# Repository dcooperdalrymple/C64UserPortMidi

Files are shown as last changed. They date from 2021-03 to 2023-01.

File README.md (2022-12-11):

# Commodore 64 User Port Midi Device
> Simple Midi Input & Output via the Commodore 64 User Port Interface<br />
> Created by D Cooper Dalrymple 2021 - [dcdalrymple.com](https://dcdalrymple.com/)<br />
> Licensed under GNU GPL V3.0<br />

I found myself in possession of a Commodore SX-64 and a desire to make music with it. After quickly finding [Cynthcart](https://www.qotile.net/cynthcart.html), I wasn't too happy about the idea of plugging both the Cynthcart cartridge and a separate Datel midi cartridge into in a [Mini X-Pander+](http://www.arkanixlabs.com/minixpander/) all sticking out of the hood of my SX-64. I had assumed that the User Port would have been a great interface for transmitting the necessary midi input data to whatever SID program you're jamming with. That's where this project comes in.

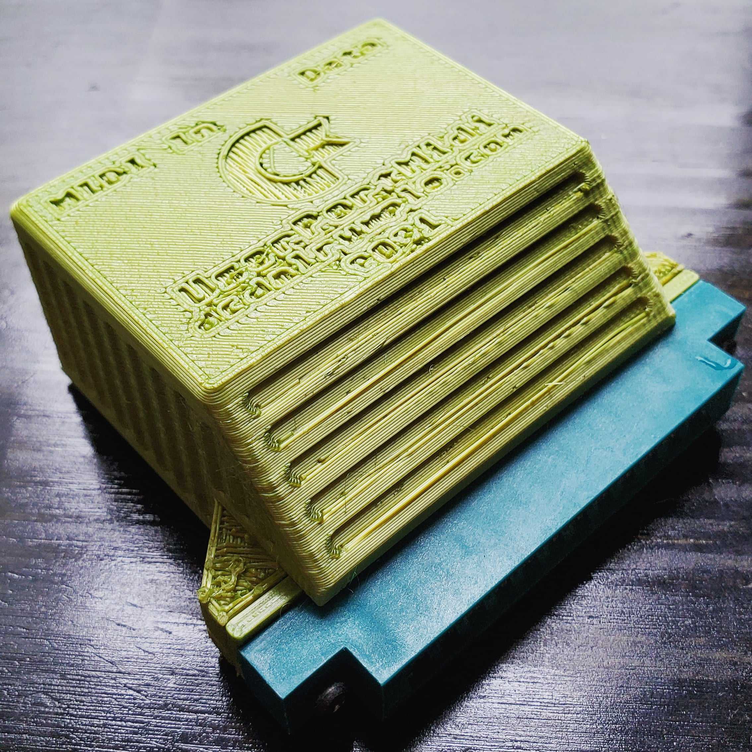
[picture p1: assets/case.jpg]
First development unit of C64UserPortMidi with 3d-printed case


## Functionality
The concept is fairly simple: the stream of data from the midi input will be piped into a buffer by the microcontroller. After representing the value of each byte on the data bus of the user port (PB0-7), it will then trigger the user port's flag interrupt (FLAG2) to indicate new data is available. The compatible Commodore software that has an interrupt registered for the user port's flag pin then adds that 8-bit data register to a data buffer. The midi information would then need to be processed by the main loop of the software. Easy peasy!

I am aware that there are serial lines available on the user port that have been used for RS-232 communication and such, but I wanted to use the least amount of resources when transferring data from the bus to the Commodore software. A simple `lda $DD01` is all that is necessary to get the full byte during a flag interrupt.

The 8 bits of the user port are bi-directionally connected to the microcontroller, and a data transfer back to the microcontroller can be flagged using the dedicated GPIO pin, PC2. This functionality can be used to send midi data back out through the Midi Out port and perform additional functionality that has yet to be developed (channel filters, etc).

## Components
The microcontroller chosen for this project is the ATtiny2313. Using this micro reduces the total BOM by not requiring an external crystal oscillator, operating at 5V, including a hardware UART controller, and having just the right amount of GPIO.

Overall, the BOM is fairly minimal and using only through-hole components for easy assembly. To quickly get started making your own, I've assembled a [Digikey shared cart](https://www.digikey.com/short/7djhm4fz) with the exact hardware requirements and all of the necessary gerber files to order your own PCBs from a distributor such as PCBway.

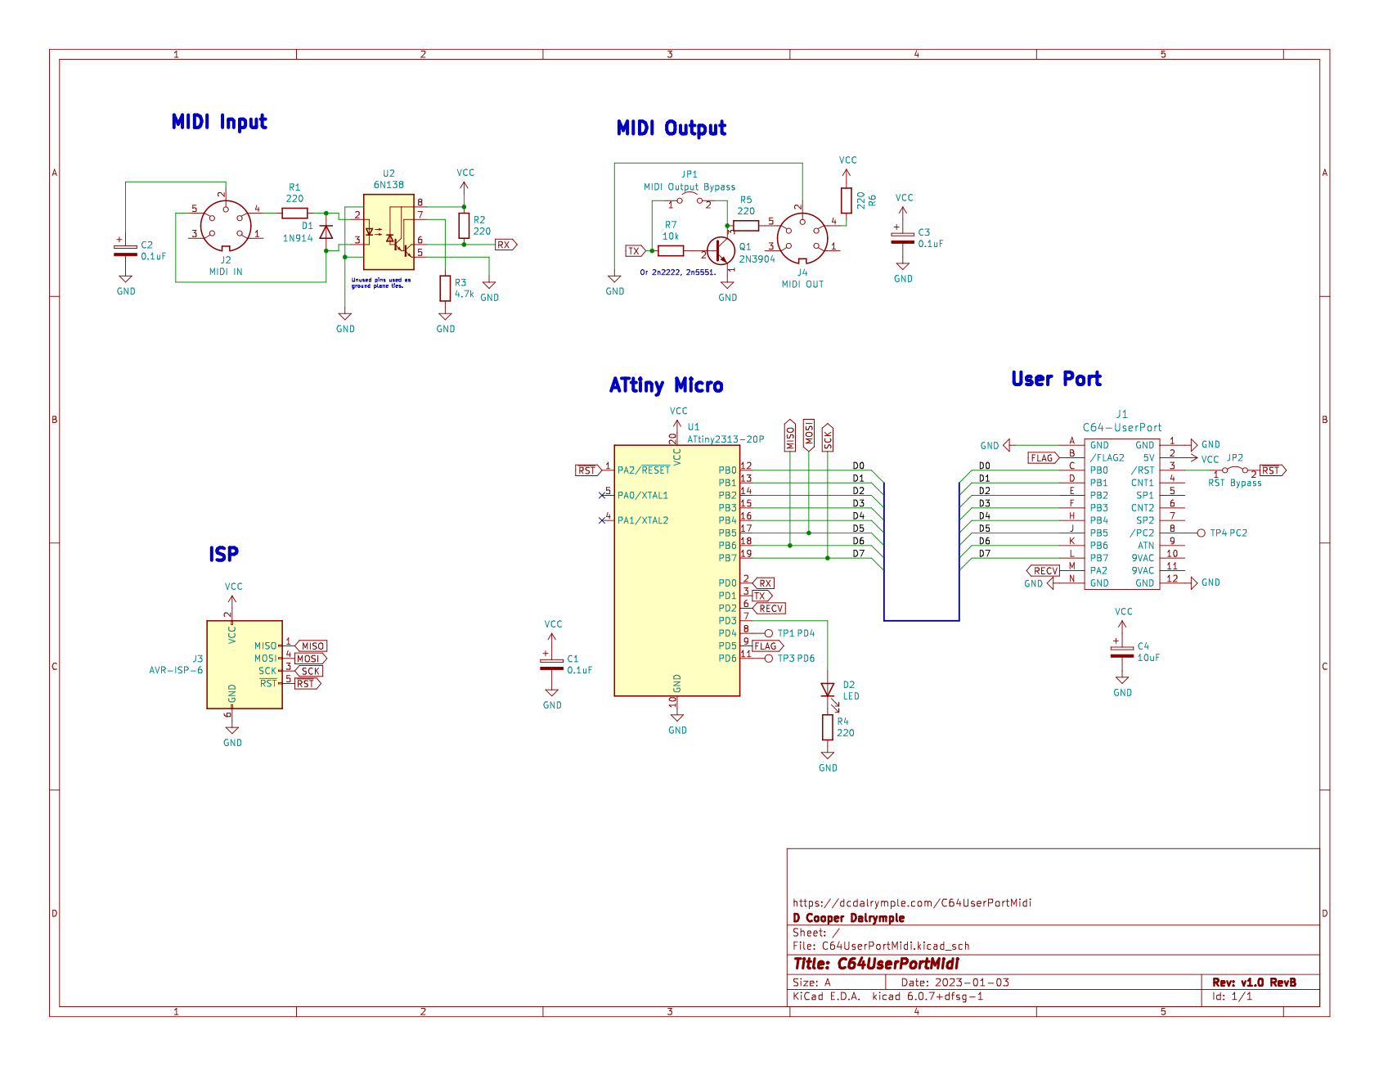
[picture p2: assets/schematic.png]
Schematic of C64UserPortMidi v1.0 RevA


## Development Status
I've just completed revision A of the hardware design which migrated from the ATtiny13 to ATtiny2313 and removed the need for a shift register. I've also added the components required MIDI output since the new microcontroller should be able to handle UART transmission with ease.

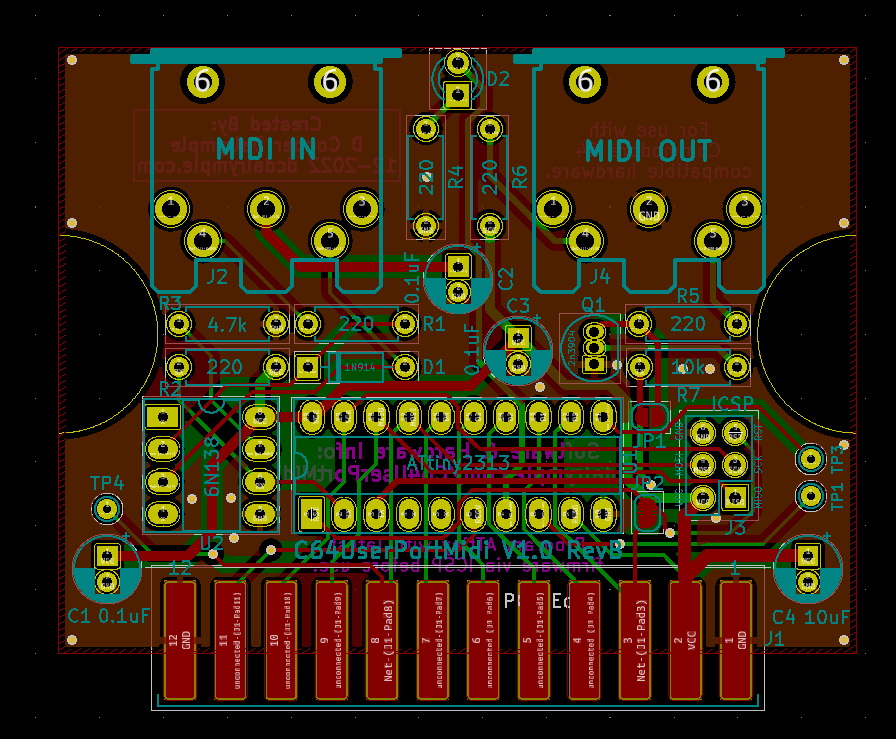
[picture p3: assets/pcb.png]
PCB Design of C64UserPortMidi v1.0 RevA


The firmware hasn't yet been updated for this new board design, but the functionality should mostly remain the same within the C64 software. I'll provide examples of bidirectional data transfer showcasing the output functionality of the new board once any bugs have been worked out.

I advise from producing your own units until the hardware and software have been fully developed.

## Software
A testing cartridge for the C64 is in development and mostly complete. This easily fits on a small 4kb/8kb lo-rom cart and could be compiled for floppy if needed. It can be run in emulation, but it isn't very useful unless the debugging data is enabled.

I plan to fork the Cynthcart repo once testing is completed to include full compatibility with this device.

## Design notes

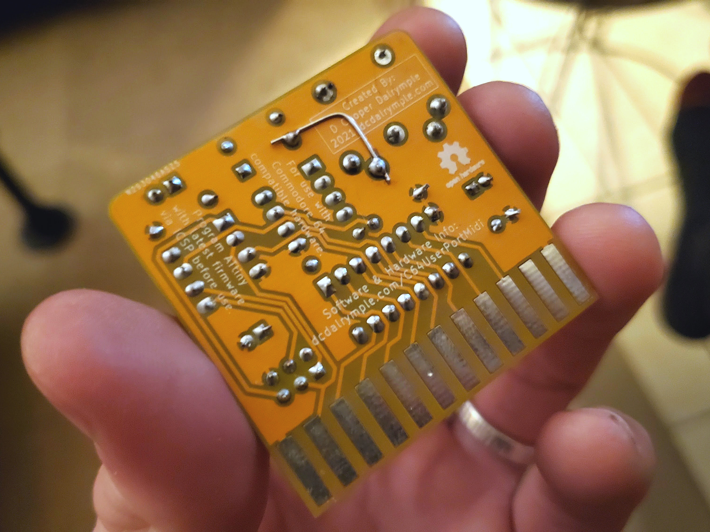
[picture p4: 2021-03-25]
assets/back.jpg

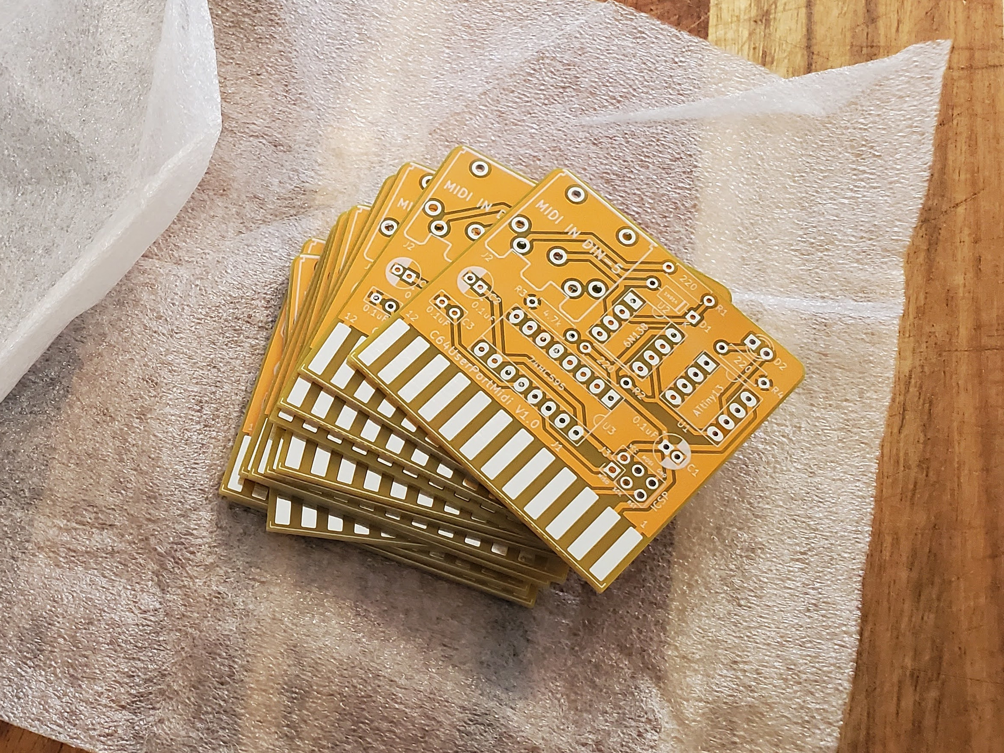
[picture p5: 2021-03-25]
assets/pcbs.jpg

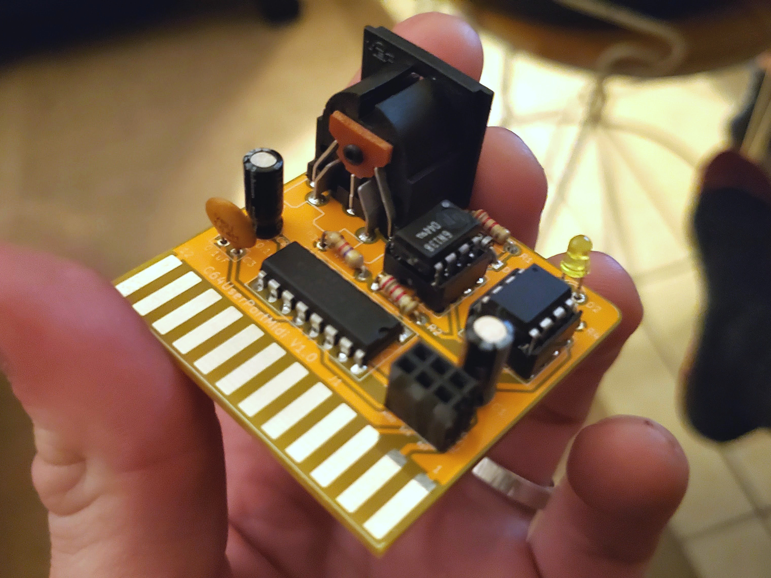
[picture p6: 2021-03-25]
assets/edge.jpg

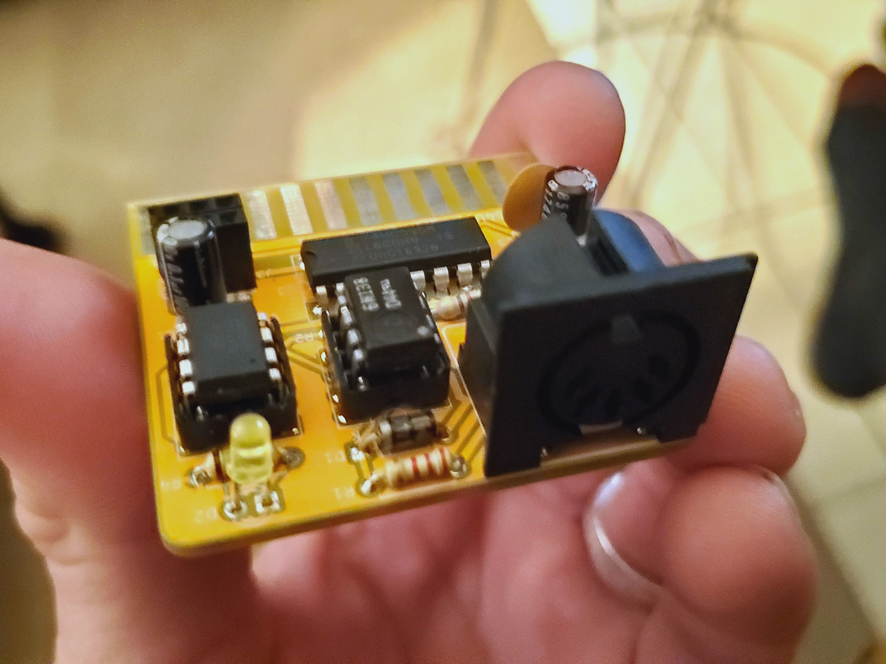
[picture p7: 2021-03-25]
assets/ports.jpg

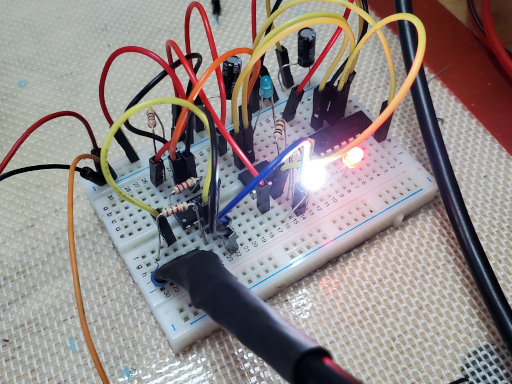
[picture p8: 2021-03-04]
assets/prototype.jpg

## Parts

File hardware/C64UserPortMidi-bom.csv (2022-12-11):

Reference | Value | Footprint | Datasheet
C1 | 0.1uF | Capacitor_THT:CP_Radial_D5.0mm_P2.00mm
C2 | 0.1uF | Capacitor_THT:CP_Radial_D5.0mm_P2.00mm
C3 | 0.1uF | Capacitor_THT:CP_Radial_D5.0mm_P2.00mm
C4 | 10uF | Capacitor_THT:CP_Radial_D5.0mm_P2.00mm
D1 | 1N914 | Diode_THT:D_DO-35_SOD27_P7.62mm_Horizontal | http://www.vishay.com/docs/85622/1n914.pdf
D2 | LED | LED_THT:LED_D3.0mm
J1 | C64-UserPort | Commodore64C:Connector_Edge_2x12_P3.96mm
J2 | MIDI IN | Video Connectors:din-5 | http://www.mouser.com/ds/2/18/40_c091_abd_e-75918.pdf
J3 | AVR-ISP-6 | Connector_PinHeader_2.54mm:PinHeader_2x03_P2.54mm_Vertical | ~
J4 | MIDI OUT | Video Connectors:din-5 | http://www.mouser.com/ds/2/18/40_c091_abd_e-75918.pdf
JP1 | MIDI Output Bypass | Jumper:SolderJumper-2_P1.3mm_Open_RoundedPad1.0x1.5mm
JP2 | RST Bypass | Jumper:SolderJumper-2_P1.3mm_Bridged_RoundedPad1.0x1.5mm
Q1 | 2N3904 | Package_TO_SOT_THT:TO-92_Inline | https://www.onsemi.com/pub/Collateral/2N3903-D.PDF
R1 | 220 | Resistor_THT:R_Axial_DIN0207_L6.3mm_D2.5mm_P7.62mm_Horizontal
R2 | 220 | Resistor_THT:R_Axial_DIN0207_L6.3mm_D2.5mm_P7.62mm_Horizontal
R3 | 4.7k | Resistor_THT:R_Axial_DIN0207_L6.3mm_D2.5mm_P7.62mm_Horizontal
R4 | 220 | Resistor_THT:R_Axial_DIN0207_L6.3mm_D2.5mm_P7.62mm_Horizontal
R5 | 220 | Resistor_THT:R_Axial_DIN0207_L6.3mm_D2.5mm_P7.62mm_Horizontal
R6 | 220 | Resistor_THT:R_Axial_DIN0207_L6.3mm_D2.5mm_P7.62mm_Horizontal
R7 | 10k | Resistor_THT:R_Axial_DIN0207_L6.3mm_D2.5mm_P7.62mm_Horizontal
TP1 | PD4 | TestPoint:TestPoint_THTPad_D1.5mm_Drill0.7mm
TP3 | PD6 | TestPoint:TestPoint_THTPad_D1.5mm_Drill0.7mm
TP4 | PA2 | TestPoint:TestPoint_THTPad_D1.5mm_Drill0.7mm
U1 | ATtiny2313-20P | Package_DIP:DIP-20_W7.62mm_Socket_LongPads | http://ww1.microchip.com/downloads/en/DeviceDoc/Atmel-2543-AVR-ATtiny2313_Datasheet.pdf
U2 | 6N138 | Package_DIP:DIP-8_W7.62mm_Socket_LongPads | http://www.onsemi.com/pub/Collateral/HCPL2731-D.pdf

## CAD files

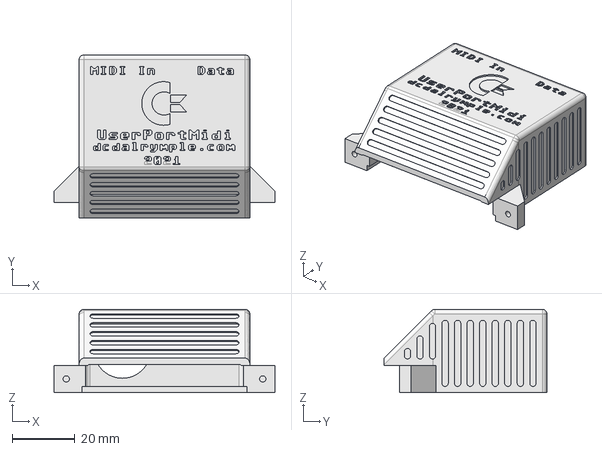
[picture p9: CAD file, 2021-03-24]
case/C64UserPortMidi-case.FCStd
70.5 x 52.0 x 26.6 mm

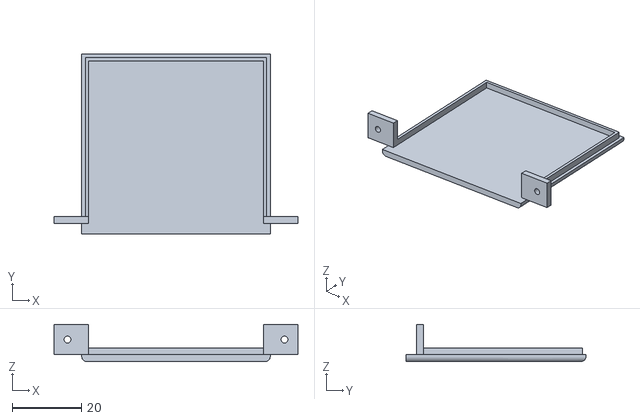
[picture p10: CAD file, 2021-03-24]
case/C64UserPortMidi-case-bottom.stl
70.5 x 52.0 x 10.8

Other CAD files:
case/C64UserPortMidi-case-top.stl

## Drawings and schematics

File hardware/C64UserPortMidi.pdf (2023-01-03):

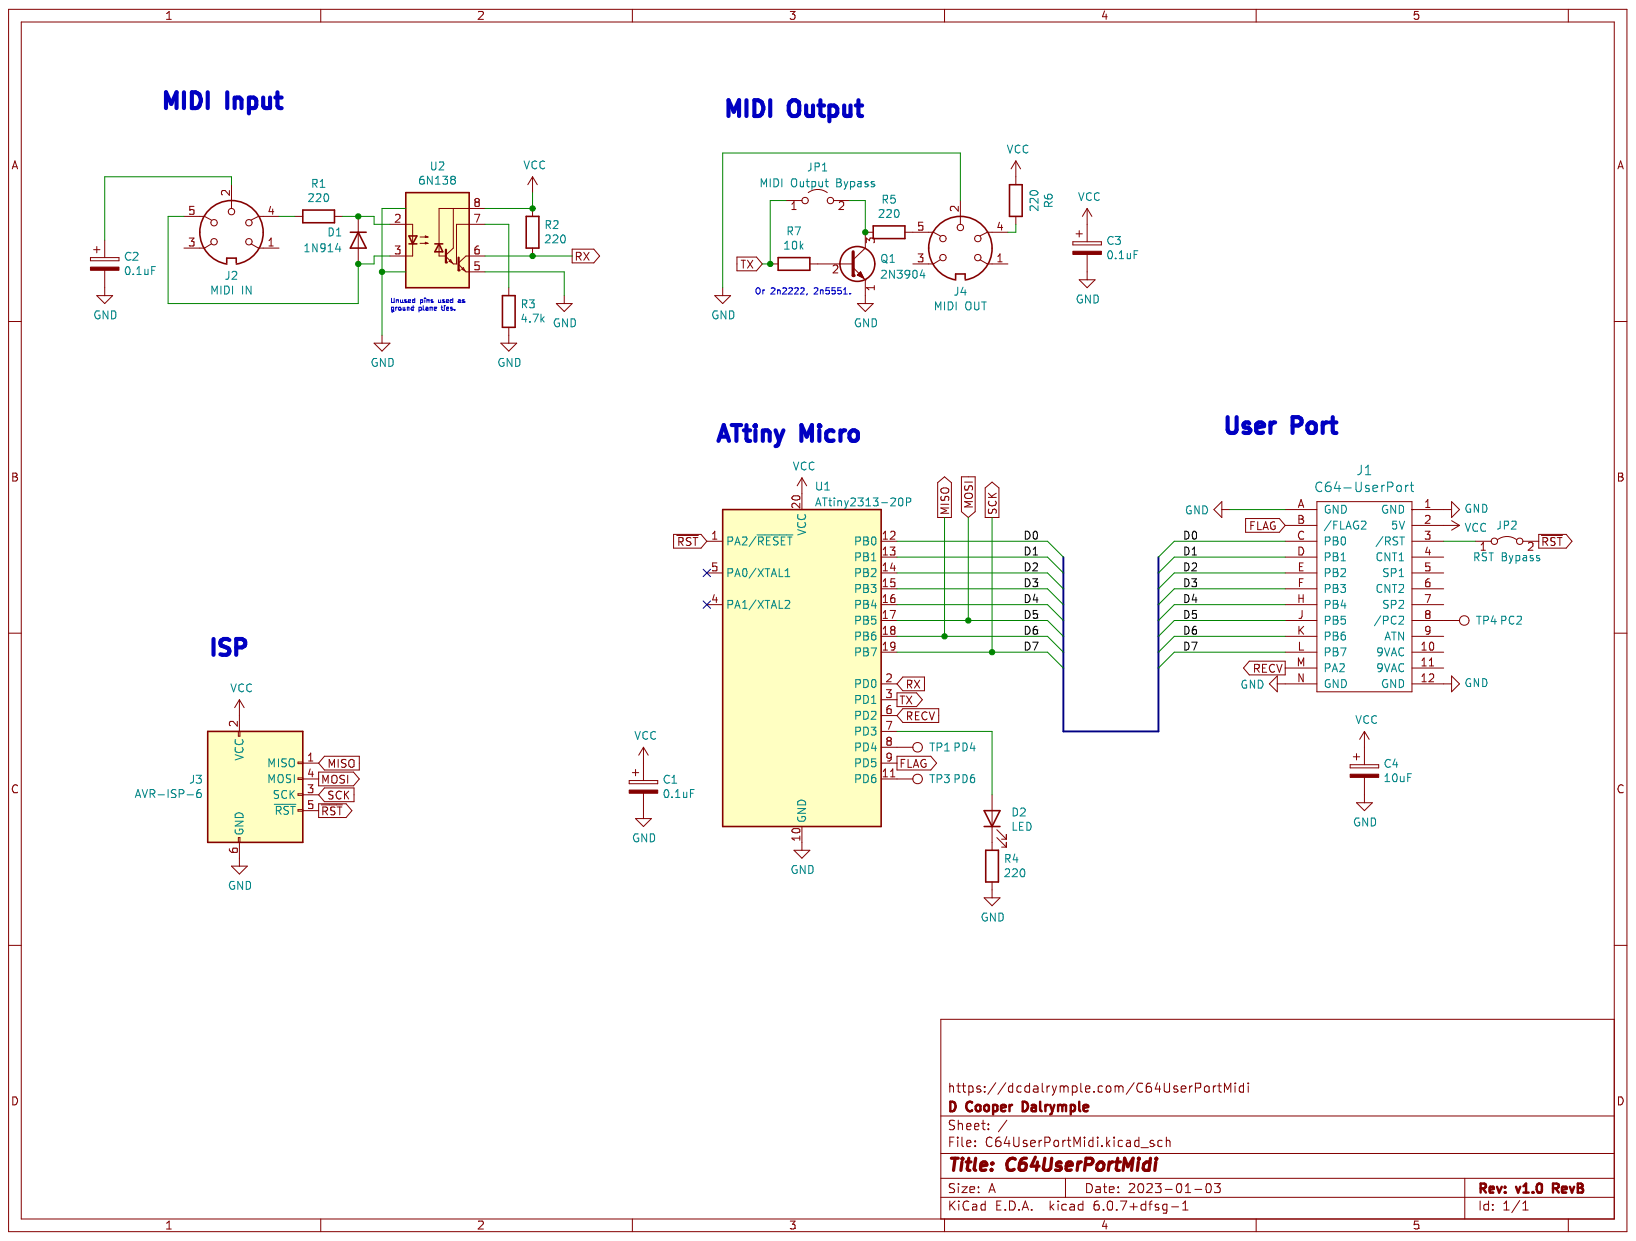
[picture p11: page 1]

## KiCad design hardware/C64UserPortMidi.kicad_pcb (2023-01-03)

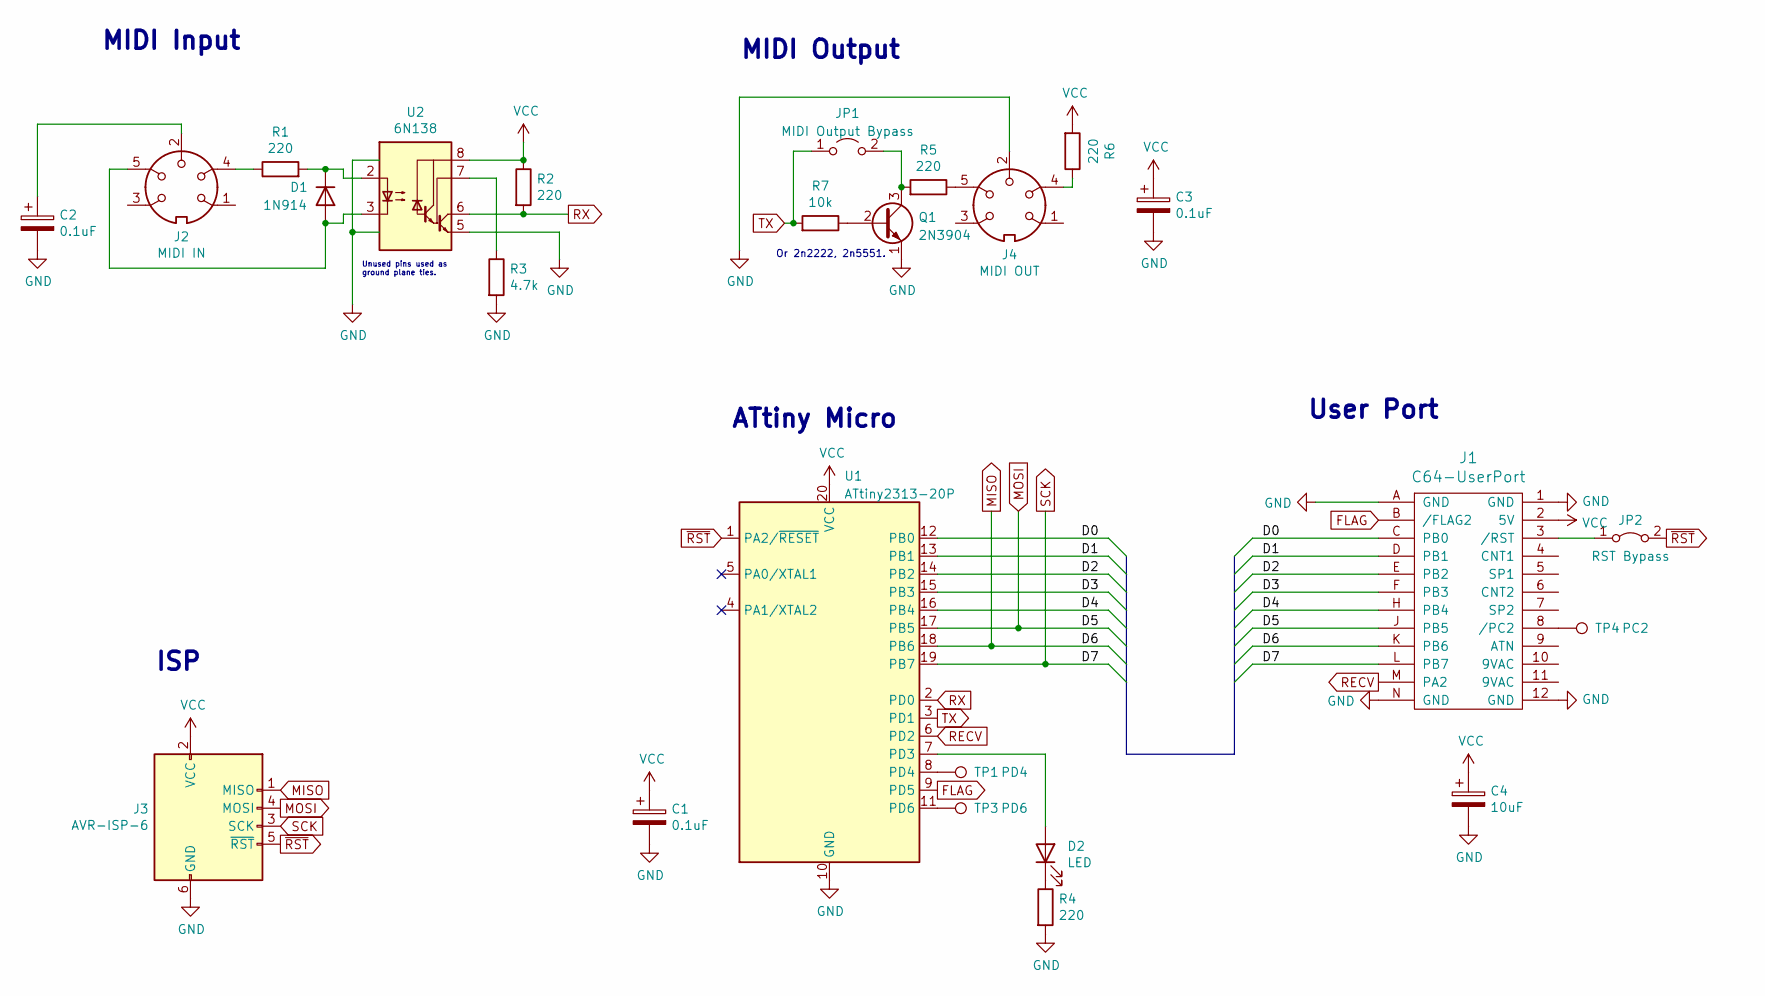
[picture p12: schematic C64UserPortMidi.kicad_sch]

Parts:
C1, C2, C3: 0.1uF; CP_Radial_D5.0mm_P2.00mm
C4: 10uF; CP_Radial_D5.0mm_P2.00mm
D1: 1N914; D_DO-35_SOD27_P7.62mm_Horizontal
D2: LED; LED_D3.0mm
J1: C64-UserPort; Connector_Edge_2x12_P3.96mm
J2: MIDI IN; din-5
J3: AVR-ISP-6; PinHeader_2x03_P2.54mm_Vertical
J4: MIDI OUT; din-5
JP1: MIDI Output Bypass; SolderJumper-2_P1.3mm_Open_RoundedPad1.0x1.5mm
JP2: RST Bypass; SolderJumper-2_P1.3mm_Bridged_RoundedPad1.0x1.5mm
Q1: 2N3904; TO-92_Inline
R1, R2, R4, R5, R6: 220; R_Axial_DIN0207_L6.3mm_D2.5mm_P7.62mm_Horizontal
R3: 4.7k; R_Axial_DIN0207_L6.3mm_D2.5mm_P7.62mm_Horizontal
R7: 10k; R_Axial_DIN0207_L6.3mm_D2.5mm_P7.62mm_Horizontal
TP1: PD4; TestPoint_THTPad_D1.5mm_Drill0.7mm
TP3: PD6; TestPoint_THTPad_D1.5mm_Drill0.7mm
TP4: PC2; TestPoint_THTPad_D1.5mm_Drill0.7mm
U1: ATtiny2313-20P; DIP-20_W7.62mm_Socket_LongPads
U2: 6N138; DIP-8_W7.62mm_Socket_LongPads

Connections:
/D0: J1.C (PB0), U1.12 (PB0)
/D1: J1.D (PB1), U1.13 (PB1)
/D2: J1.E (PB2), U1.14 (PB2)
/D3: J1.F (PB3), U1.15 (PB3)
/D4: J1.H (PB4), U1.16 (PB4)
FLAG: J1.B (/FLAG2), U1.9 (PD5)
GND: C1.2, C2.2, C3.2, C4.2, J1.1 (GND), J1.12 (GND), J1.A (GND), J1.N (GND), J3.6 (GND), J4.2, Q1.1 (E), R3.2, R4.2, U1.10 (GND), U2.1 (NC), U2.4 (NC), U2.5 (GND)
MISO: J1.K (PB6), J3.1 (MISO), U1.18 (PB6)
MOSI: J1.J (PB5), J3.4 (MOSI), U1.17 (PB5)
unnamed: C2.1, J2.2
unnamed: D1.1 (K), R1.2, U2.2 (C1)
unnamed: D1.2 (A), J2.5, U2.3 (C2)
unnamed: D2.1 (K), R4.1
unnamed: D2.2 (A), U1.7 (PD3)
unnamed: J1.3 (/RST), JP2.1 (A)
unnamed: J1.8 (/PC2), TP4.1
unnamed: J2.4, R1.1
unnamed: J4.4, R6.1
unnamed: J4.5, R5.1
unnamed: JP1.2 (B), Q1.3 (C), R5.2
unnamed: Q1.2 (B), R7.1
unnamed: R3.1, U2.7 (VO1)
unnamed: TP1.1, U1.8 (PD4)
unnamed: TP3.1, U1.11 (PD6)
RECV: J1.M (PA2), U1.6 (PD2)
RX: R2.2, U1.2 (PD0), U2.6 (VO2)
SCK: J1.L (PB7), J3.3 (SCK), U1.19 (PB7)
TX: JP1.1 (A), R7.2, U1.3 (PD1)
VCC: C1.1, C3.1, C4.1, J1.2 (5V), J3.2 (VCC), R2.1, R6.2, U1.20 (VCC), U2.8 (VCC)
~RST: J3.5 (~RST), JP2.2 (B), U1.1 (PA2/~RESET)

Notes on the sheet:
MIDI Input
MIDI Output
Or 2n2222, 2n5551.
User Port
ATtiny Micro
Unused pins used as ground plane ties.
ISP

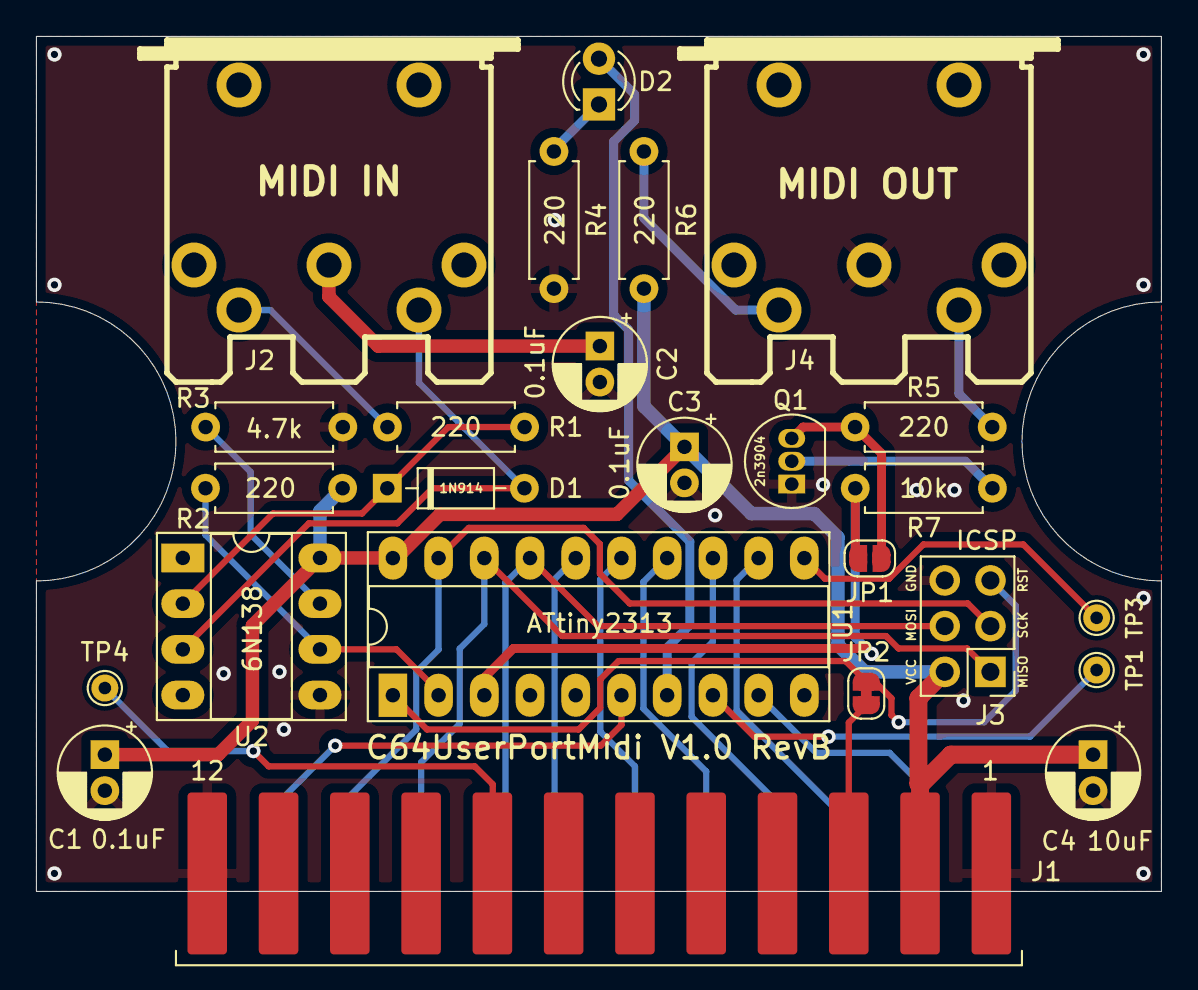
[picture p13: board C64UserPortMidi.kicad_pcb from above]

Board: 2 copper layers, 62.5 x 47.5 mm, 25 parts (0 on the bottom side), 30 nets.

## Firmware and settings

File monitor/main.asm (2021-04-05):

; C64 UserPort MIDI Monitor
; Created by D Cooper Dalrymple 2021 - dcdalrymple.com
; Licensed under GNU LGPL V3.0
; Created: 25-02-2021
; Last revision: 04-04-2021

    processor 6502
    include "c64.h"

DEBUG   = 0

;===================
; Program Constants
;===================

; Data Printing
HEX_LINE_MAX    = #10
DEC_LINE_MAX    = #8

; MIDI Parsing
COMM_NOTE_OFF       = #$08
COMM_NOTE_ON        = #$09
COMM_PRESSURE       = #$0A
COMM_CC             = #$0B
COMM_PC             = #$0C
COMM_CHAN_PRESSURE  = #$0D
COMM_PITCH_BEND     = #$0E
;COMM_SYSTEM         = #$0F

COMM_NOTE_OFF_LEN       = #2
COMM_NOTE_ON_LEN        = #2
COMM_PRESSURE_LEN       = #2
COMM_CC_LEN             = #2
COMM_PC_LEN             = #1
COMM_CHAN_PRESSURE_LEN  = #1
COMM_PITCH_BEND_LEN     = #2


; Variables in RAM

    SEG.U zp_vars
    org $00FB ; Only 4 bytes available in zero page

temp    ds 4

    SEG.U zp_vars2
    org $02A7 ; 88 bytes of zero page

hexstr  ds 5
buflen  ds 1
buffer  ds 16
index   ds 1
mode    ds 1 ; Bit #6 & #7: %00 = hex, %01 = dec, %10 = midi

linelen ds 1

mcomm   ds 1 ; Midi Command
mchan   ds 1 ; Midi Channel
mlen    ds 1 ; Midi Data Length
mdata   ds 2 ; Midi Data

;================
; Cart header
;================

    SEG
    org LOROM

    include "autostart.asm"

;====================================
; User Port Flag NMI Interrupt Setup
;====================================

flag_init:
    sei ; Disable interrupts

    ; Start buffer at 0
    lda #0
    sta buflen

    ; Set interrupt handler address
    lda #<flag_handler
    sta NMIVEC+0
    lda #>flag_handler
    sta NMIVEC+1

    ; Disable all other interrupts
    lda #%01111111 ; Bit #7 is fill bit
    sta CIA1ICR
    sta CIA2ICR
    lda #0
    sta $D01A ; Raster Interrupts

    ; Enable Flag Interrupt
    lda #%10010000
    sta CIA2ICR

    cli ; Enable interrupts

;================
; User Port GPIO
;================

port_init:
    lda #0
    sta CIA2DDRB ; Set all as inputs on port b

    lda #%00000100
    sta CIA2DDRA ; Set PA2 as output
    sta CIA2A ; Start high to indicate that we're not in the middle of an interrupt

;=================
; Keyboard Config
;=================

key_init:

    ; Keyboard buffer of 1 (kinda disable)
    lda #1
    sta KEYLEN

    ; Disable key repeats
    lda #%01000000
    sta KEYREP

    ; Set initial mode (hex)
    lda #%00000000
    sta mode

    lda #0
    sta buflen

#if DEBUG == 1
    ; Test buffer data
    lda #%10000000
    sta mode
    lda #14
    sta buflen
    lda #$9B
    sta buffer+0
    lda #$47
    sta buffer+1
    lda #$9B
    sta buffer+2
    lda #$00
    sta buffer+3
    lda #$7B
    sta buffer+4
    lda #$9B
    sta buffer+5
    lda #$48
    sta buffer+6
    lda #$9B
    sta buffer+7
    lda #$00
    sta buffer+8
    lda #$7B
    sta buffer+9

    lda #$BB
    sta buffer+10
    lda #$7F
    sta buffer+11
    lda #$BB
    sta buffer+12
    lda #$00
    sta buffer+13
#endif

;=====================
; Program Info Header
;=====================

screen_init:

    ; Set my preferred colors ;)
    lda #COL_BLACK
    sta BDCOL
    sta BKCOL
    lda #COL_GREEN
    sta CHCOL

    ; Set cursor to 0x0
    lda #0
    sta CURCOL
    sta CURROW

    ; Reset line length
    lda #0
    sta linelen

screen_clear:
    lda #SPACE
    ldx #0 ; loops around to $FF as decrementing
screen_clear_loop:
    sta $0400,x
    sta $0500,x
    sta $0600,x
    sta $0700,x
    dex
    bne screen_clear_loop

print_info:
    ; Print info header data
    ldx #<info_str
    ldy #>info_str
    jsr Print

    bit mode
    bvs print_mode_dec
    bmi print_mode_midi

print_mode_hex:
    ldx #<mode_hex_str
    ldy #>mode_hex_str
    jmp print_mode

print_mode_dec:
    ldx #<mode_dec_str
    ldy #>mode_dec_str
    jmp print_mode

print_mode_midi:
    ldx #<mode_midi_str
    ldy #>mode_midi_str

print_mode:
    jsr Print

;=====================
; Keyboard Processing
;=====================

key_check:
    jsr SCNKEY
    jsr GETIN

    cmp #KEY_NA
    beq buffer_check

    cmp #KEY_F1
    beq mode_hex
    cmp #KEY_F3
    beq mode_dec
    cmp #KEY_F5
    beq mode_midi

    jmp buffer_check

mode_hex:
    lda #0
    jmp mode_set
mode_dec:
    lda #%01000000
    jmp mode_set
mode_midi:
    lda #%10000000
mode_set:
    sta mode
    jmp screen_init ; Reset screen

;========================
; MIDI Buffer Processing
;========================

buffer_check:
    lda buflen
    beq key_check

    bit mode
    bvs buffer_dec
    bmi buffer_midi

buffer_hex:
    ldy #0
    sty index
buffer_hex_loop:

    ; Ignore system messages
    lda buffer,y
    and #$f0
    cmp #$f0
    beq buffer_hex_skip

    lda buffer,y
    jsr PrintHex

buffer_hex_skip:
    inc index
    ldy index
    cpy buflen
    bne buffer_hex_loop

    jmp buffer_reset

buffer_dec:
    ldy #0
    sty index
buffer_dec_loop:

    ; Ignore system messages
    lda buffer,y
    and #$f0
    cmp #$f0
    beq buffer_dec_skip

    lda buffer,y
    jsr PrintDec

buffer_dec_skip:
    inc index
    ldy index
    cpy buflen
    bne buffer_dec_loop

    jmp buffer_reset

buffer_midi:
    ldy #0
    sty index
buffer_midi_loop:
    lda buffer,y
    and #%10000000
    beq buffer_midi_skip

buffer_midi_status:
    ; command
    lda buffer,y
    and #%01110000 ; remove msb status flag
    REPEAT 4
    lsr
    REPEND
    sta mcomm

    ; channel
    lda buffer,y
    and #$0f
    sta mchan

    ldy mcomm
    lda midi_comm_len,y
    sta mlen

    clc
    adc index
buffer_midi_wait:
    cmp buflen
    bcs buffer_midi_wait

    ldx #0
buffer_midi_data:
    inc index
    ldy index

    lda buffer,y
    sta mdata,x

    inx
    cpx mlen
    bne buffer_midi_data

    jsr PrintMidi

buffer_midi_skip:
    inc index
    ldy index
    cpy buflen
    bne buffer_midi_loop

    ;jmp buffer_reset

buffer_reset:
    lda #0
    sta buflen

    jmp key_check ; Go back to keyboard loop after flushing out buffer

;========================
; Flag Interrupt Handler
;========================

flag_handler:

    ; Save registers (only a & y)
    pha
    tya
    pha

    ; Set PA2 low to indicate that we're processing byte
    lda #%00000000
    sta CIA2A

    ; Read User Port GPIO byte
    lda CIA2B

    ; Store in buffer
    ldy buflen
    sta buffer,y

    ; Increment buffer length
    inc buflen

    ; Set PA2 high to indicate that we're done with the interrupt
    lda #%00000100
    sta CIA2A

    ; Restore registers
    pla
    tay
    pla

    bit CIA2ICR ; Tell interrupt to reset
    rti ; Return to main process

;====================
; String & Midi Data
;====================

info_str:
    .byte $0E,#CLS ; Change case & cls
    dc.b "c64 uSERpORT mIDI mONITOR",#EOL
    dc.b "d cOOPER dALRYMPLE",#EOL
    dc.b "v0.3 - 2021.04.04",#EOL,#EOL
    .byte #EOF

mode_hex_str:
    dc.b "hEX mODE",#EOL,#EOL
    .byte #EOF

mode_dec_str:
    dc.b "dECIMAL mODE",#EOL,#EOL
    .byte #EOF

mode_midi_str:
    dc.b "mIDI mODE",#EOL,#EOL
    .byte #EOF

hex_prepend:
    dc.b "$"
hex_data:
    dc.b "0123456789abcdef"

midi_comm_len:
    .byte #COMM_NOTE_OFF_LEN
    .byte #COMM_NOTE_ON_LEN
    .byte #COMM_PRESSURE_LEN
    .byte #COMM_CC_LEN
    .byte #COMM_PC_LEN
    .byte #COMM_CHAN_PRESSURE_LEN
    .byte #COMM_PITCH_BEND_LEN

midi_comm_strs:
    .byte #<midi_comm_note_off_str
    .byte #>midi_comm_note_off_str
    .byte #<midi_comm_note_on_str
    .byte #>midi_comm_note_on_str
    .byte #<midi_comm_pressure_str
    .byte #>midi_comm_pressure_str
    .byte #<midi_comm_cc_str
    .byte #>midi_comm_cc_str
    .byte #<midi_comm_pc_str
    .byte #>midi_comm_pc_str
    .byte #<midi_comm_chan_pressure_str
    .byte #>midi_comm_chan_pressure_str
    .byte #<midi_comm_pitch_bend_str
    .byte #>midi_comm_pitch_bend_str
midi_comm_note_off_str:
    dc.b "nOTE oFF        ",#EOF
midi_comm_note_on_str:
    dc.b "nOTE oN         ",#EOF
midi_comm_pressure_str:
    dc.b "pRESSURE        ",#EOF
midi_comm_cc_str:
    dc.b "cONTROL cHANGE  ",#EOF
midi_comm_pc_str:
    dc.b "pROGRAM cHANGE  ",#EOF
midi_comm_chan_pressure_str:
    dc.b "cHANNEL pRESSURE",#EOF
midi_comm_pitch_bend_str:
    dc.b "pITCH bEND      ",#EOF

midi_chan_str:
    dc.b "c: ",#EOF

midi_data_str:
    dc.b "d: ",#EOF

    include "routines.asm"

    org (HIROM-1) ; Lo: $8000, Hi: $A000
    .byte $00
    END

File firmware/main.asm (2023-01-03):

; Title: C64 UserPort MIDI
; Author: D Cooper Dalrymple
; Website: https://dcdalrymple.com/C64UserPortMidi/
; Created: 24/02/2021
; Updated: 13/12/2022
; HW Version: v1.0 RevA
; SW Version: v1.1

.nolist
.include "tn2313def.inc"
.list

.equ LED = PD3

.def tmp = r16
.def i = r17
.def j = r18
.def k = r19
.def data = r20

.dseg
.org SRAM_START

.org $0000 ; Hard Reset
    rjmp Init

.org INT0addr
    rjmp BusReceive

.org $000A ; Start of program code

.include "delay.inc"
.include "bus.inc"
.include "midi.inc"

Init:
    ; Set Stack Pointer to top of RAM
    ldi tmp, low(RAMEND)
    out SPL, tmp

    ; Configure led output
    sbi DDRD, LED
    sbi PORTD, LED ; Start high to indicate initialization

    ; Initialize components
    rcall BusInit
    rcall MidiInit

    cbi PORTD, LED ; Initialization process complete

    ; Enable Interrupts
    sei

Buffer:
    ; Populate buffer with incoming midi bytes
    rcall MidiReceive

    ldi tmp, LOW(SRAM_START)
    cpse YL, tmp ; NOTE: Relative branches aren't working for some reason
    rjmp Buffer_process ; Data in buffer
    rjmp Buffer ; Keep waiting for buffer

    ; TODO: Wait until enough valid midi data to process and check channel, etc.

Buffer_process:
    sbi PORTD, LED

    ldi XH, HIGH(SRAM_START)
    ldi XL, LOW(SRAM_START)
Buffer_write:

    ; Load current data byte and transmit to bus
    ld data, X
    rcall BusTransmit

    ; Load up next byte if we still haven't hit index
    inc XL
    cpse XL, YL
    rjmp Buffer_write

Buffer_clear:
    cbi PORTD, LED
    rcall MidiClear
    rjmp Buffer

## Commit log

2021-02-25 Initial commit.
    [C64UserPortMidi.kicad_pcb, C64UserPortMidi.sch]
2021-02-25 Moved KiCad project to separate folder.
    [C64UserPortMidi.kicad_pcb, C64UserPortMidi.sch]
2021-03-02 First version of hardware pcb design completed.
    [C64UserPortMidi-B_Cu.gbl, C64UserPortMidi-B_Mask.gbs, C64UserPortMidi-B_SilkS.gbo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]
2021-03-03 Added simple UART echo test.
2021-03-03 Added data led and latch filtering capacitor to hardware design.
    [C64UserPortMidi-B_Cu.gbl, C64UserPortMidi-B_Mask.gbs, C64UserPortMidi-B_SilkS.gbo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]
2021-03-04 New readme, updated schematic assets, and BOM.
    [C64UserPortMidi-bom.csv]
2021-03-09 Fixed pin number mixup from schematic symbol to pcb footprint on midi connector.
    [C64UserPortMidi.kicad_pcb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]
2021-03-10 First rendition of C64 Midi Monitor. Mostly operational. Only showing hex data currently. I plan to add more parsing options with f-keys.
2021-03-24 C64 monitor software interrupt improvements and debug data.
2021-03-24 3d-printable case for user port dongle.
    [C64UserPortMidi-case-bottom.stl, C64UserPortMidi-case-top.stl, C64UserPortMidi-case.FCStd]
2021-03-24 Simple ATtiny13 interrupt test.
2021-03-25 Conversion of firmware and tests to AVR assembly. Still needs testing.
    [delay.ods, timing.ods]
2021-04-05 Alterations to hardware to allow better handshaking between c64 and attiny. Flag code removed in favor of combined latch. Improved delay routines. Swapped flag test to transfer test for maximum speed.
    [C64UserPortMidi.sch, delay.ods]
2021-04-27 Improvements to MIDI test. Still needs work on receive interrupt.
2022-12-08 Interrupt midi test.
2022-12-08 Removed ESP8266 kicad submodule.
2022-12-08 Updated hardware design files for KiCad 6.0.
    [C64UserPortMidi.kicad_pcb, C64UserPortMidi.kicad_sch, C64UserPortMidi.sch]
2022-12-11 New hardware design update. Version 1.0 Revision A.
    [C64UserPortMidi-B_Cu.gbl, C64UserPortMidi-B_Mask.gbs, C64UserPortMidi-B_SilkS.gbo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]
2022-12-15 Rename latch to flag in schematic.
    [C64UserPortMidi.kicad_sch]
2022-12-15 Changed ISP device to USBtinyISP.
2023-01-03 Removed midi buffer from uart processing.
2023-01-03 Added led indication to transfer test.
2023-01-03 Fixed PA2 error in schematic, rerouted traces, and regenerated gerber files.
    [C64UserPortMidi-B_Cu.gbl, C64UserPortMidi-B_Mask.gbs, C64UserPortMidi-B_Silkscreen.gbo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]
